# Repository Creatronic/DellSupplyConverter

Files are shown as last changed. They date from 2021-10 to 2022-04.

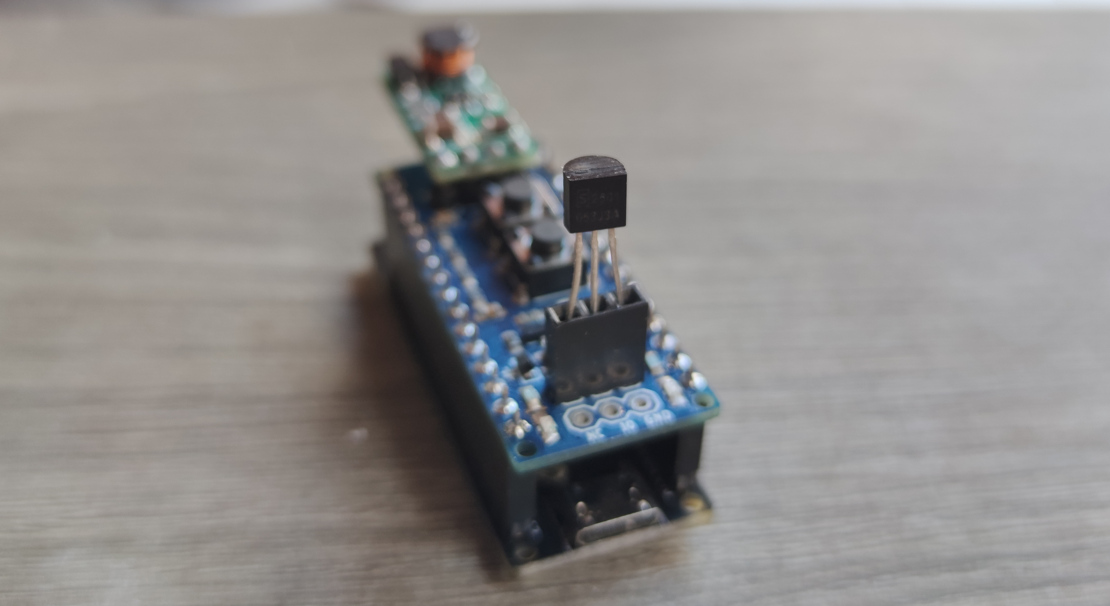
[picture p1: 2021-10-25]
Photos/IMG_20211024_102310.jpg

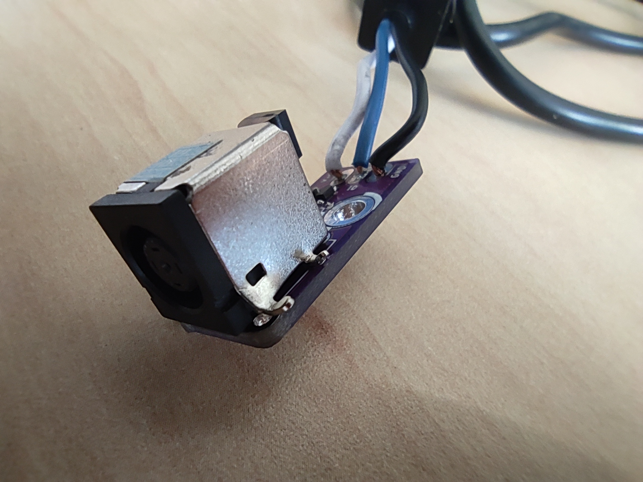
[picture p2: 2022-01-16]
Photos/IMG_20211026_142549_1.jpg

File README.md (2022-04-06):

# DellSupplyConverter
 Transform your old Dell charger to be usable on new Dell laptop
 
# About hardware
* PCB before 1.3 have been tested and are not ok against Dell connector footprint.
* V1.3 has not been tested yet (I hope it's the good one this time ...)
 
 # More infos
 https://blog.creatronic.fr/hacker-les-chargeurs-dell/

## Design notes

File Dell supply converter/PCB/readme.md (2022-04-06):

V1.0 and V1.1 => bad Dell connector footprint
V1.3 => not tested yet

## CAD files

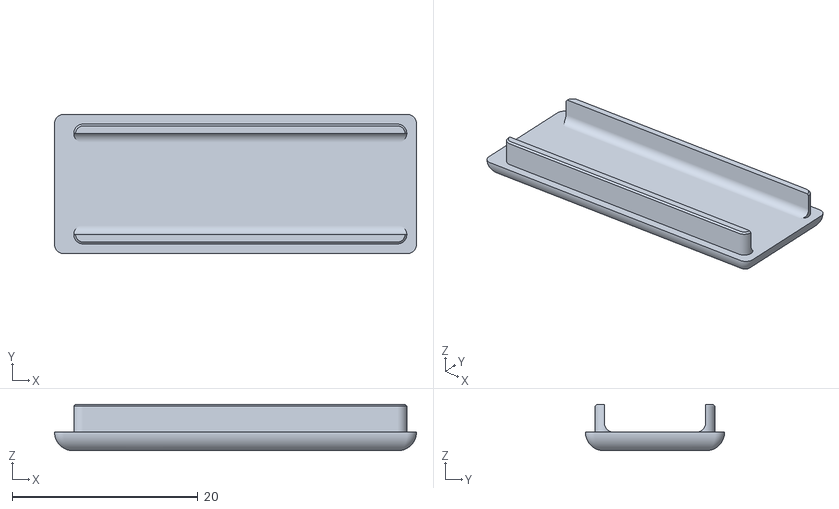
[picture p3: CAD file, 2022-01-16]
Dell supply converter/Case/Cover.stl
39.0 x 15.0 x 5.00

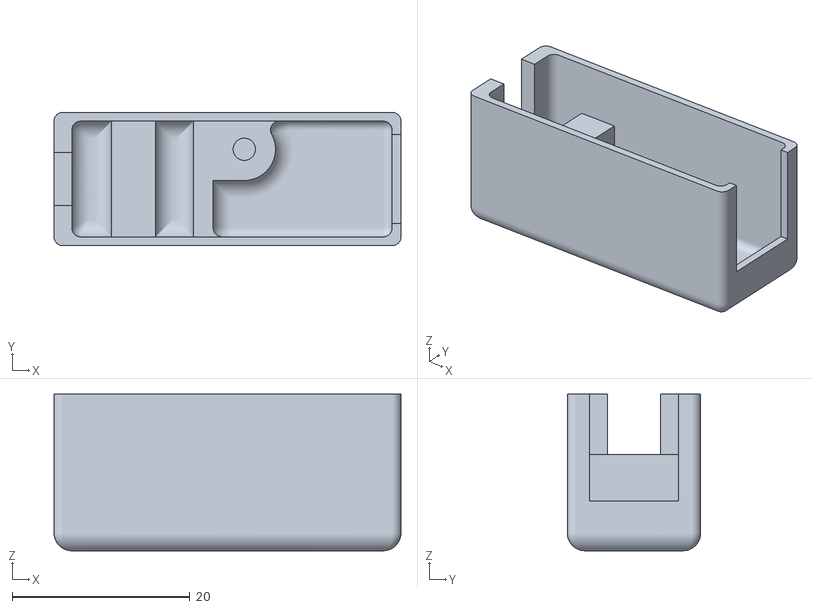
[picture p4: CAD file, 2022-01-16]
Dell supply converter/Case/Case.stl
39.0 x 15.0 x 17.6

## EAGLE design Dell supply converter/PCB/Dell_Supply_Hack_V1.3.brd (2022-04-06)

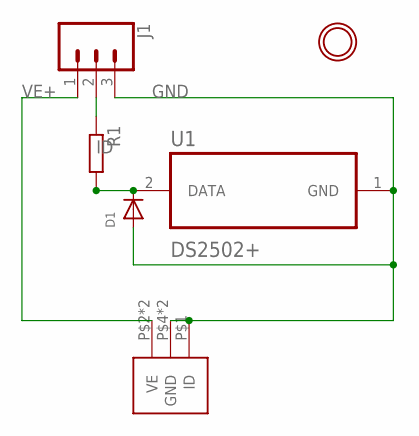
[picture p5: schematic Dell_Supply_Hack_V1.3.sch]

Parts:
D1: DIODESOD-323F; SOD-323F
J1: CONN_03LONGPADS; 1X03_LONGPADS
R1: R-EU_R0603; R0603
U1: DS2502+; TO92127P495H695-3
U$1: DELL_CON; DELL_CON_01
U$2: MOUNTING_HOLE; MOUNTINGHOLE_3.0_PLATED

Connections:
GND: D1.A, J1.3, U1.1 (GND), U$1.P$1 (ID), U$1.P$4 (GND), U$1.P$5 (GND)
ID: J1.2, R1.1
unnamed: D1.C, R1.2, U1.2 (DATA)
VE+: J1.1, U$1.P$2 (VE), U$1.P$3 (VE)

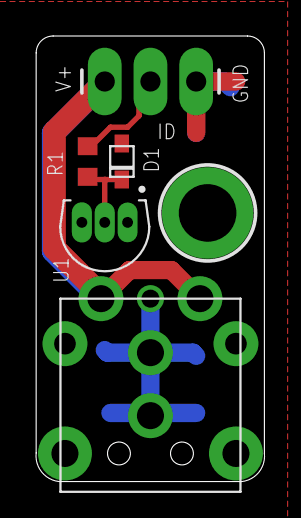
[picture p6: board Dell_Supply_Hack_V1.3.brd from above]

Board: 2 copper layers, 12.7 x 24.8 mm, 6 parts (0 on the bottom side), 4 nets.

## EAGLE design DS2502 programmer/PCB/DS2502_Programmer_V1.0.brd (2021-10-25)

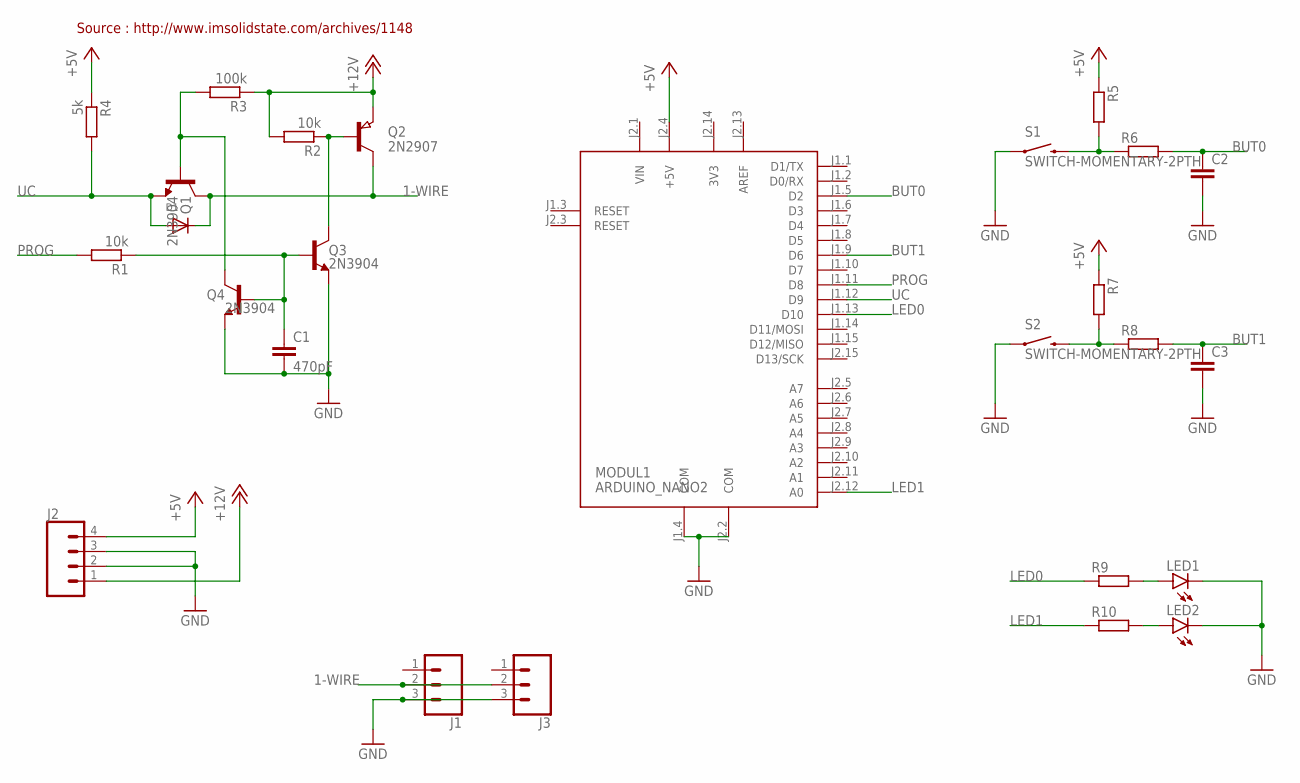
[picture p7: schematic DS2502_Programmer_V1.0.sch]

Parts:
C1: 470pF; C0603
C2, C3: C-EUC0603; C0603
D1: DIODESOD-523; SOD-523
J1, J3: CONN_03; 1X03
J2: CONN_04; 1X04
LED1, LED2: LEDCHIP-LED0805; CHIP-LED0805
MODUL1: ARDUINO_NANO2
Q1, Q3, Q4: 2N3904; SOT23-3
Q2: 2N2907; SOT23
R1, R2: 10k; R0603
R3: 100k; R0603
R4: 5k; R0603
R5, R6, R7, R8, R9, R10: R-EU_R0603; R0603
S1, S2: SWITCH-MOMENTARY-2PTH; TACTILE-PTH

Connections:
1-WIRE: D1.K (C), J1.2, J3.2, Q1.3 (C), Q2.3 (C)
3V3: MODUL1.J2.14 (3V3)
+5V: J2.4, MODUL1.J2.4 (+5V), R4.1, R5.1, R7.1
+12V: J2.1, Q2.2 (E), R2.2, R3.1
AREF: MODUL1.J2.13 (AREF)
BUT0: C2.1, MODUL1.J1.5 (D2), R6.2
BUT1: C3.1, MODUL1.J1.9 (D6), R8.2
GND: C1.2, C2.2, C3.2, J1.3, J2.2, J2.3, J3.3, LED1.C, LED2.C, MODUL1.J1.4 (COM), MODUL1.J2.2 (COM), Q3.2 (E), Q4.2 (E), S1.1, S2.1
LED0: MODUL1.J1.13 (D10), R9.1
LED1: MODUL1.J2.12 (A0), R10.1
unnamed: Q2.1 (B), Q3.3 (C), R2.1
unnamed: R5.2, R6.1, S1.3 (2)
unnamed: R7.2, R8.1, S2.3 (2)
unnamed: Q1.1 (B), Q4.3 (C), R3.2
unnamed: LED1.A, R9.2
unnamed: LED2.A, R10.2
unnamed: C1.1, Q3.1 (B), Q4.1 (B), R1.1
PROG: MODUL1.J1.11 (D8), R1.2
UC: D1.A, MODUL1.J1.12 (D9), Q1.2 (E), R4.2
VIN: MODUL1.J2.1 (VIN)

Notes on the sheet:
Source : http://www.imsolidstate.com/archives/1148

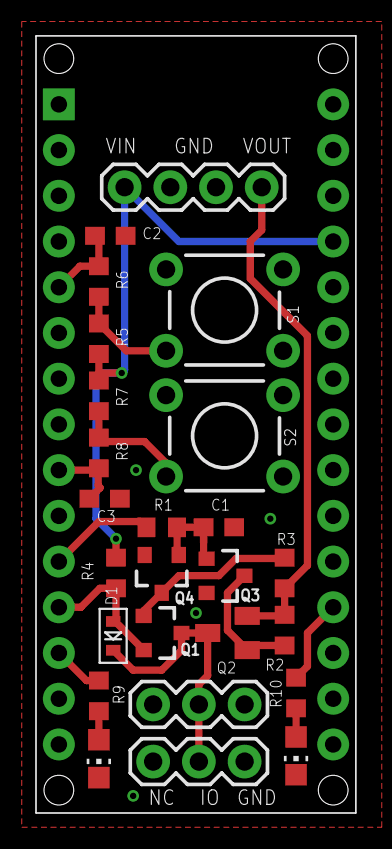
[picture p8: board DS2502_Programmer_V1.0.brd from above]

Board: 2 copper layers, 17.8 x 43.2 mm, 28 parts (0 on the bottom side), 17 nets.

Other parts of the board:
U$1: CC_BY_NC_SA_1
U$3: CREATRONIC_4

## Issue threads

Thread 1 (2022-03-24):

more info

ipatch, 2022-03-24:
as somebody with an old dell laptop, e4300. and who is fortunate enough to have the original charger, but also has a higher wattage charger that will not work with the laptop due to the stupid dell serial authentication via the dallas chip (or whatnot) i'm curious about this project, and wonder is any other info about this? or am i suppose to sift around the repo and figure things out on my own?

looks like a cool project nonetheless

battosai30, 2022-03-25:
Hi,
Owww you pointed that I forgot to give the link to my post in my blog ^^'

https://blog.creatronic.fr/hacker-les-chargeurs-dell/

But it's in french, if you need any help => ask ;)

ipatch, 2022-03-25:
thanks for sharing the link. 🙏 that's a cool 😎 write up you did there. i saw / came across a similar write up linked on hackaday where the person removed the dallas chip from his original charger and soldered directly to the power socket (daughter board) inside the laptop, thus i believe always sending the write "serial" (using that term loosely) back to the bios so essentially any and every charger in theory would work with the laptop.

one more question (if you don't mind), have you come across anyone or any writeups about people modifying the bios to allow any and all (serial / response code)?

to me that'd seem like the ideal solution, no opening up the laptop soldering chips to daughter boards, or making adapters, but rather "updating" the bios so i can accept whatever serial is sent back from the dallas chip kindof like a `*.*` 🤔

battosai30, 2022-03-26:
I agree it would be a better solution but :

- BIOS are usually not open source so ...
- Modifying a BIOS is a big risk : if you miss something, no more computer ...
- It means modify all Dell BIOS (each one is different)
- I'm not sure that is the BIOS which manage that. BIOS shows information but it's not sure that it's it that control the charging stage, and my bet is that it's not. BIOS just displays information given by the chip which manage charge. But it's a guess ... base what I would do if I was working at Dell Inc xD

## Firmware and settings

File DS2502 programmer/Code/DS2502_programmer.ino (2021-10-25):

/*** Pin mapping ***/
#define PROG_PIN 8
#define ONEWIRE_PIN 9
#define BUTTON_0 2
#define BUTTON_1 6
#define LED0 10
#define LED1 A0

// This is the magic string Dell laptops need to see from the device in order to not go into limp home mode
// The interesting bit is the wattage 090 followed by the voltage 1950 and the amperage 4.6
char *progStr = "DELL00AC090195046CN09T";
#define ProgLocation (0x00)

#include <OneWire.h>

#define DS2502DevID 0x09

#define READ_ROM   0x33
#define MATCH_ROM  0x55
#define SKIP_ROM   0xCC
#define SEARCH_ROM 0xF0
#define ROM_SZ 8  // 8 bytes of laser etched ROM data , LSB = 0x09 == DS2502

// DS250x Memory commands -- can only be executed after one of the above ROM commands has been executed properly
#define READ_MEMORY  0xF0
#define READ_STATUS  0xAA
#define WRITE_STATUS 0x55
#define WRITE_MEMORY 0x0F

#define ProgPulseUs 500    // length of time 12V prog pulse needs to be applied for 

OneWire ds(ONEWIRE_PIN);             // OneWire bus on digital pin 6

void setup() {

  Serial.begin(115200);
  /*delay(2000);
    Serial.println("Hello !");*/
  pinMode(LED0, OUTPUT);
  pinMode(LED1, OUTPUT);

  pinMode(PROG_PIN, OUTPUT);
  digitalWrite(PROG_PIN, LOW);

  if (isDSPresent())
  {
    digitalWrite(LED1, HIGH);
    readStatus();
  }

}
void readStatus()
{

  byte leemem[12];

  Serial.println("Reading Status");

  ds.reset();
  ds.skip();                      // Skip ROM search, address the device no matter what
  leemem[0] = READ_STATUS;        // command
  leemem[1] = 0;       // low address byte
  leemem[2] = 0;                  // High address byte, always 0 for 2502
  ds.write(leemem[0], 1);       // Read data command, leave ghost power on
  ds.write(leemem[1], 1);       // LSB starting address, leave ghost power on
  ds.write(leemem[2], 1);       // MSB starting address, leave ghost power on

  byte crc = ds.read();             // DS250x generates a CRC for the command we sent, we assign a read slot and store it's value
  byte crc_calc = OneWire::crc8(leemem, 3);  // We calculate the CRC of the commands we sent using the library function and store it

  if (crc_calc != crc)        // Then we compare it to the value the ds250x calculated, if it fails, we print debug messages and abort
  {
    Serial.println("Invalid command CRC!");
    Serial.print("Calculated CRC:");
    Serial.println(crc_calc, HEX);   // HEX makes it easier to observe and compare
    Serial.print("DS250x readback CRC:");
    Serial.println(crc, HEX);
  }

  Serial.println("Status is: ");

  byte data[8];

  for (int i = 0; i < 8; i++)
  {
    data[i] = ds.read();
    Serial.print(data[i], HEX);
    Serial.print(" ");
  }
  Serial.println("");
}
void loop() {

  if (digitalRead(BUTTON_0) == LOW)
  {
    readDSMemory();
    while (digitalRead(BUTTON_0) == LOW);
    delay(100);
  }

  if (digitalRead(BUTTON_1) == LOW)
  {
    writeDSMemory();
    while (digitalRead(BUTTON_1) == LOW);
    delay(100);
  }
}

void readDSMemory()
{

  byte leemem[12];

  Serial.println("Reading Memory");

  ds.reset();
  ds.skip();                      // Skip ROM search, address the device no matter what
  leemem[0] = READ_MEMORY;        // command
  leemem[1] = ProgLocation;       // low address byte
  leemem[2] = 0;                  // High address byte, always 0 for 2502
  ds.write(leemem[0], 1);       // Read data command, leave ghost power on
  ds.write(leemem[1], 1);       // LSB starting address, leave ghost power on
  ds.write(leemem[2], 1);       // MSB starting address, leave ghost power on

  byte crc = ds.read();             // DS250x generates a CRC for the command we sent, we assign a read slot and store it's value
  byte crc_calc = OneWire::crc8(leemem, 3);  // We calculate the CRC of the commands we sent using the library function and store it

  if (crc_calc != crc)        // Then we compare it to the value the ds250x calculated, if it fails, we print debug messages and abort
  {
    Serial.println("Invalid command CRC!");
    Serial.print("Calculated CRC:");
    Serial.println(crc_calc, HEX);   // HEX makes it easier to observe and compare
    Serial.print("DS250x readback CRC:");
    Serial.println(crc, HEX);
  }

  Serial.println("Data is: ");

  byte data[32];

  for (int i = 0; i < 32; i++)
  {
    data[i] = ds.read();
    //Serial.print(data[i], HEX);
    Serial.write(data[i]);
    Serial.print(" ");
  }
  Serial.println("");
}

void writeDSMemory()
{

  uint8_t leemem[12];

  for (uint8_t i = 0; i < strlen(progStr); i++) {
    
    ds.reset();
    ds.skip();

    Serial.println("PROG Memory");

    leemem[0] = WRITE_MEMORY;       // command to initiate a write seq using array for later CRC calc
    leemem[2] = 0;                  // high address is always 0
    leemem[1] = ProgLocation + i;
    leemem[3] = (uint8_t)progStr[i];

    for(uint8_t i=0;i<4;i++)
    {
      ds.write(leemem[i]);
    }
    
    uint8_t crc = ds.read();

    uint8_t crc_calc = OneWire::crc8(leemem, 4);  // We calculate the CRC of the commands we sent using the library function and store it

    if (crc_calc != crc)        // Then we compare it to the value the ds250x calculated, if it fails, we print debug messages and abort
    {
      Serial.println("Invalid command CRC!");
      Serial.print("Calculated CRC:");
      Serial.println(crc_calc, HEX);   // HEX makes it easier to observe and compare
      Serial.print("DS250x readback CRC:");
      Serial.println(crc, HEX);
    }

    progPulse();
    
    uint8_t data = ds.read();
    
    Serial.print("Programmed data read back : ");
    Serial.print("adress=0x");
    Serial.print(leemem[1],HEX);
     Serial.print(" char=");
    Serial.write(data);
    Serial.print(" value=0x");
    Serial.println(data, HEX);

  }
}

byte isDSPresent()
{

  byte data[32];

  if (ds.reset())
  {

    Serial.println("device present");

    ds.write(READ_ROM, 1);
    Serial.println("ROM  Data is: ");
    for (int i = 0; i < 8; i++)
    {
      data[i] = ds.read();
      Serial.print(data[i], HEX);
      Serial.print(" ");
    }

    Serial.println(".");
    byte crc_calc = OneWire::crc8(data, 7);

    if (crc_calc == data[7] )
    {
      Serial.println("ROM CRC matches ");
      if (data[0] != DS2502DevID)
      {
        Serial.println("Device ID does not match DS2502");
      }
      return 1;
    }
    else
    {
      Serial.println("ROM CRC failed");
    }

  }
  return 0;
}

void progPulse()
{
  
  digitalWrite(PROG_PIN, HIGH);
  delayMicroseconds(ProgPulseUs);
  digitalWrite(PROG_PIN, LOW);
  delayMicroseconds(100);
  
}

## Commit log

2022-01-16 Add stl
    [Case.stl, Cover.stl]
2022-01-16 Add gerbers + pcb
    [Dell_Supply_Hack_V1.1.brd, Dell_Supply_Hack_V1.1.sch]
2022-04-06 add v1.3
    [Dell_Supply_Hack_V1.3.brd, Dell_Supply_Hack_V1.3.sch]

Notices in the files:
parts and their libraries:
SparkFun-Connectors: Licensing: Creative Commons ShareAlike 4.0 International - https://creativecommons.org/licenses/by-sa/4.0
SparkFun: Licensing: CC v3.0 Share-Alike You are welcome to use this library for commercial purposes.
